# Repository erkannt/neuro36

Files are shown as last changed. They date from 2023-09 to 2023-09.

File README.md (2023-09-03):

# neuro36

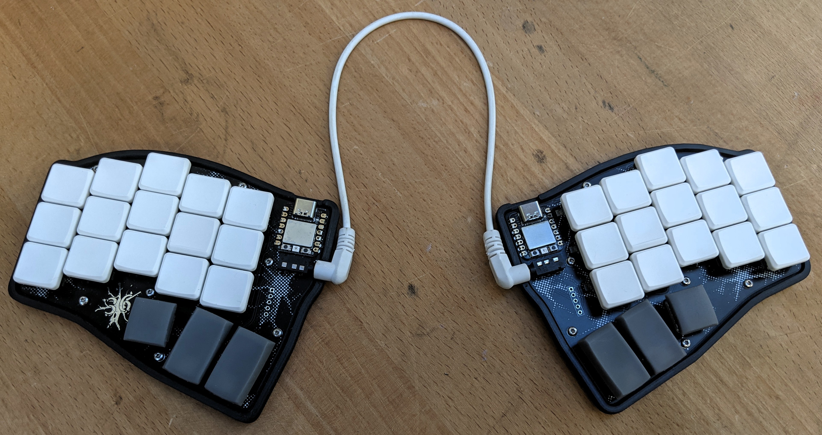
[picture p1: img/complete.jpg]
top down image of neuro36 split keyboard


- 36 key
- reversible PCB
- Xiao Seed RP2040 mcu
- choc-spaced
- remaining pins broken out on right hand  
  (hope was to add trackball)
- low profile printed case
- press fit travel protector
- silkscreen of real neurons  
  (EM image taken by my partner)
- hotswap or soldered mount of main 30 keys
- thumb keys can be soldered in either orientation

## Goals

I wanted a keyboard I could travel with. I need 36 keys and like to have larger keys to rest my thumbs on (probably due my journy having been Ergodox -> gergo).

I wanted to learn KiCAD and thanks to all the amazing open source keyboards out there it was a breeze.

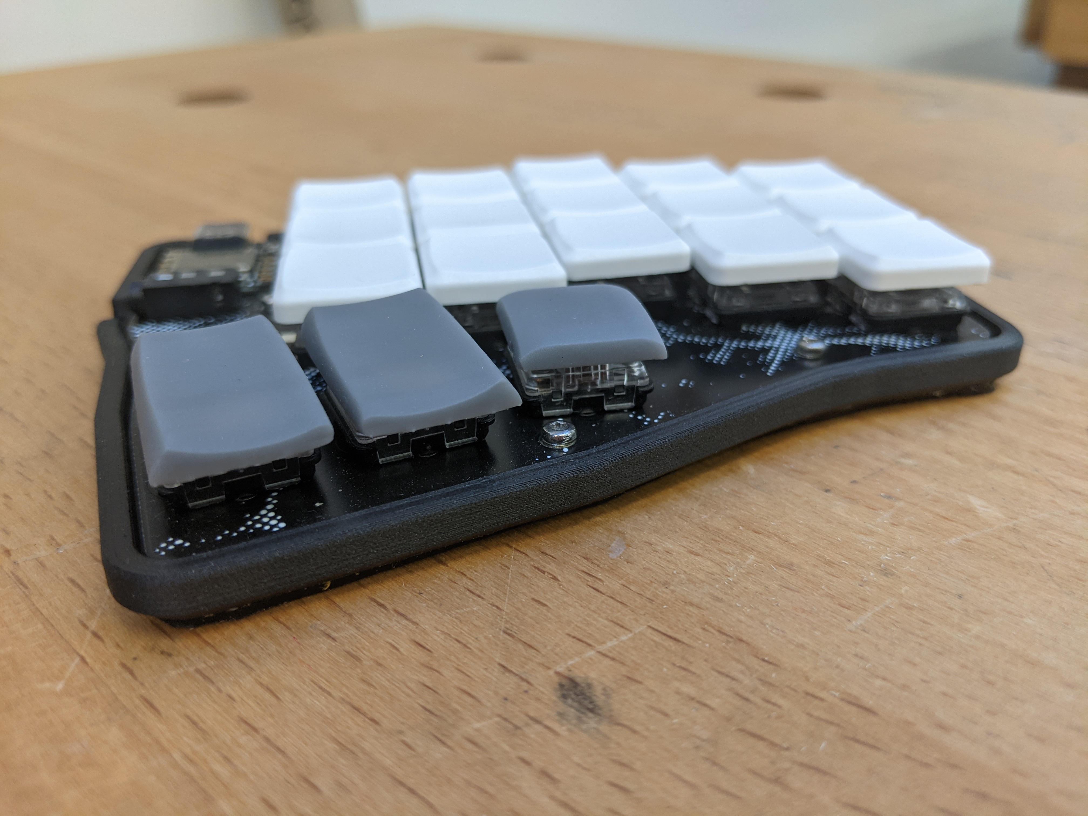
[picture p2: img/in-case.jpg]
case close up

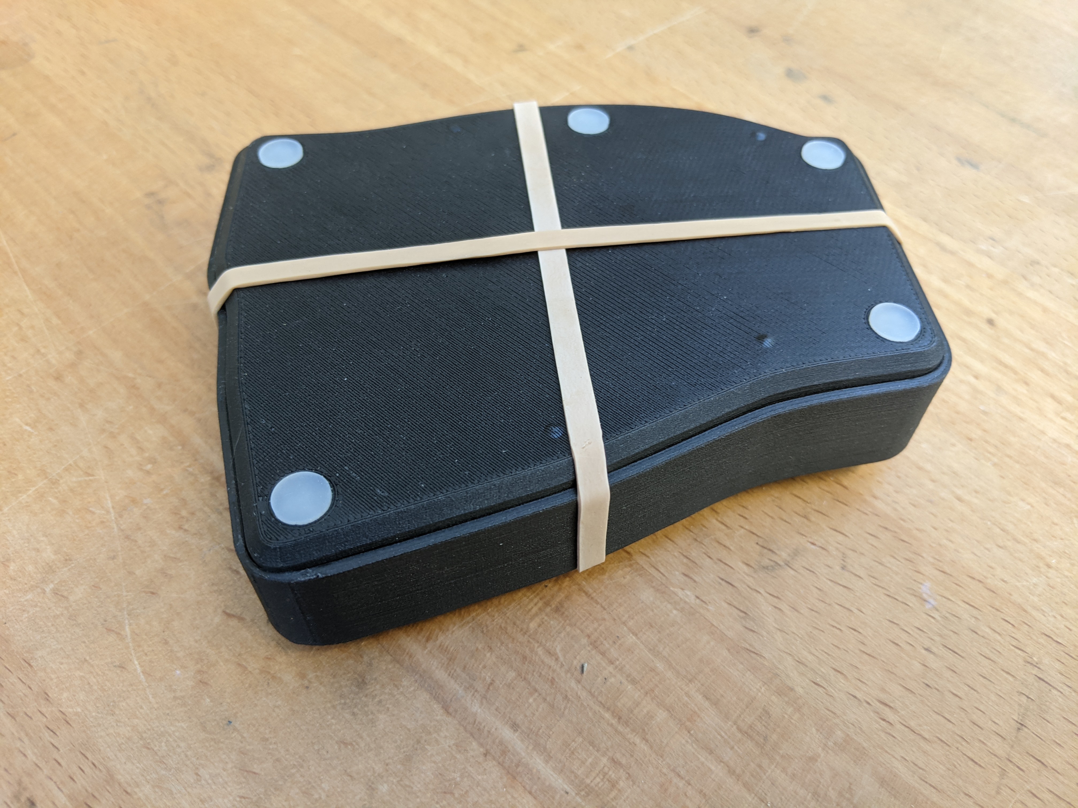
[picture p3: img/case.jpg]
case


## Making one

The [jlcpcb folder](/jlcpcb/) is what I sent off for manufacturing.
Five PCBs (enough for two keyboards) cost me 14.22 GBP incl. shipping and taxes.

The case is printable without supports, the travel protector needs supports. Make sure you have good bed adhesion and a warped print will give you a wobbly case.

Apart from the PCBs you will need:

- 36 choc switches
- keycaps (my thumbs are: [1u chicago steno](https://www.printables.com/model/158865-chicago-steno-low-profile-keycaps-kailh-choc/files#preview:file-oSJYS) and [1.5u chicago steno](https://www.printables.com/model/235527-thumb-15u-90deg-rotated-stem-fixed#preview:file-UjejR))
- TRRS cable
- heat press inserts (M2(ID) x 3.2mm(OD))
- screws (M2 x 5)
- TRRS jacks THT
- 1N4148WS SOD-323

I picked a very small diode footprint by accident. I'd suggest going for something larger if you are up for tweaking the KiCAD project.

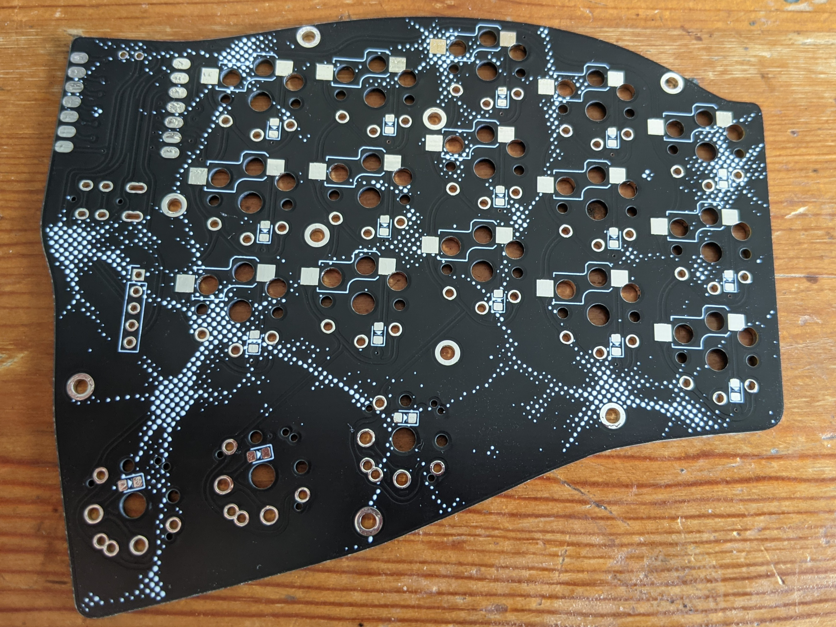
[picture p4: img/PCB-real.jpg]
neurons on pcb

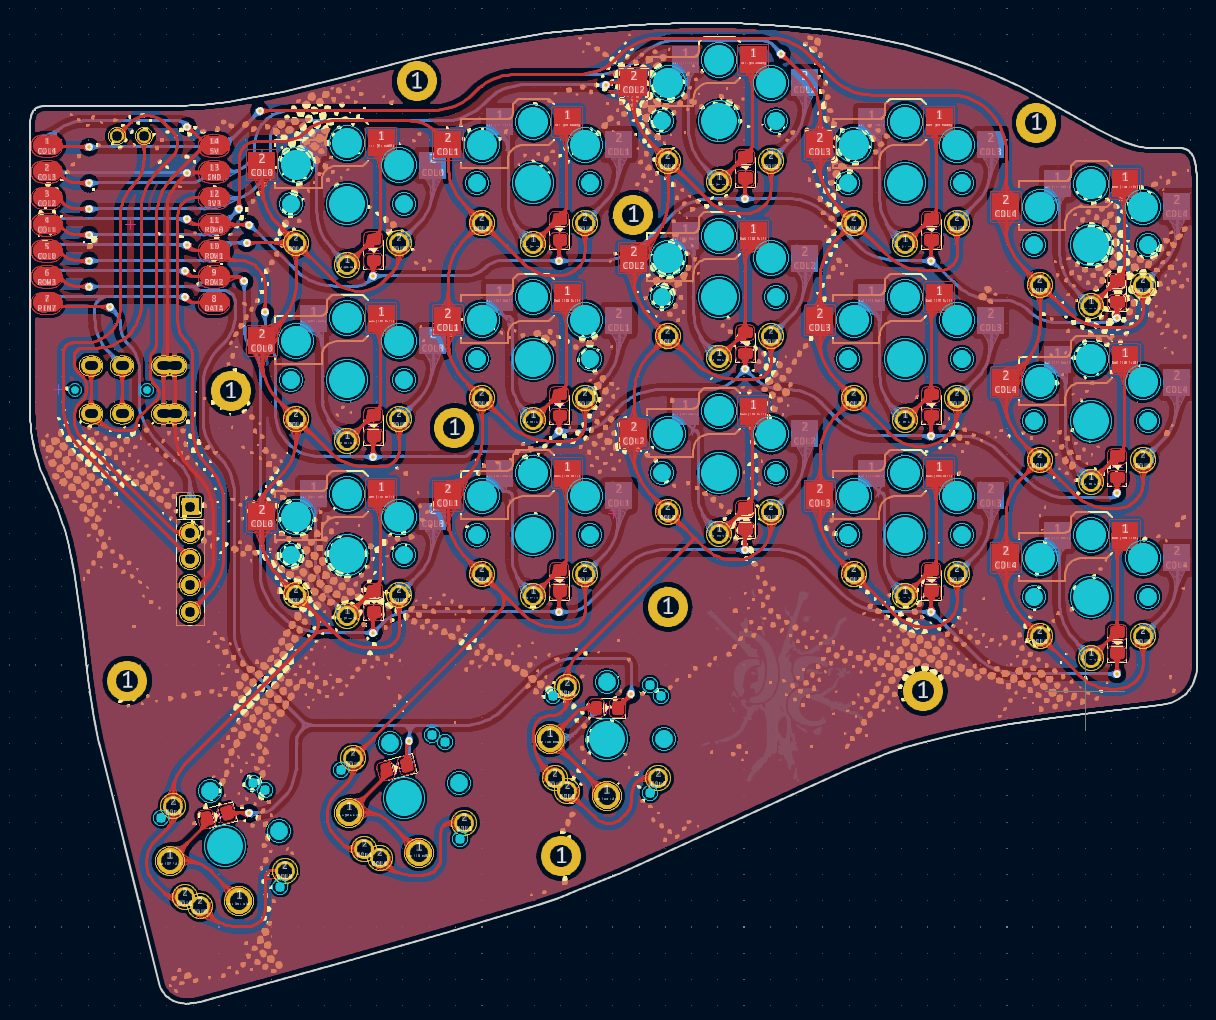
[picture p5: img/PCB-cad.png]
PCB in kicad


## Firmware

You can use my [unmerged QMK branch](https://github.com/erkannt/qmk_firmware/tree/neuro36/keyboards/neuro36) for this keyboard.

Someday I might try to get this merged.

Here is my current keymap.

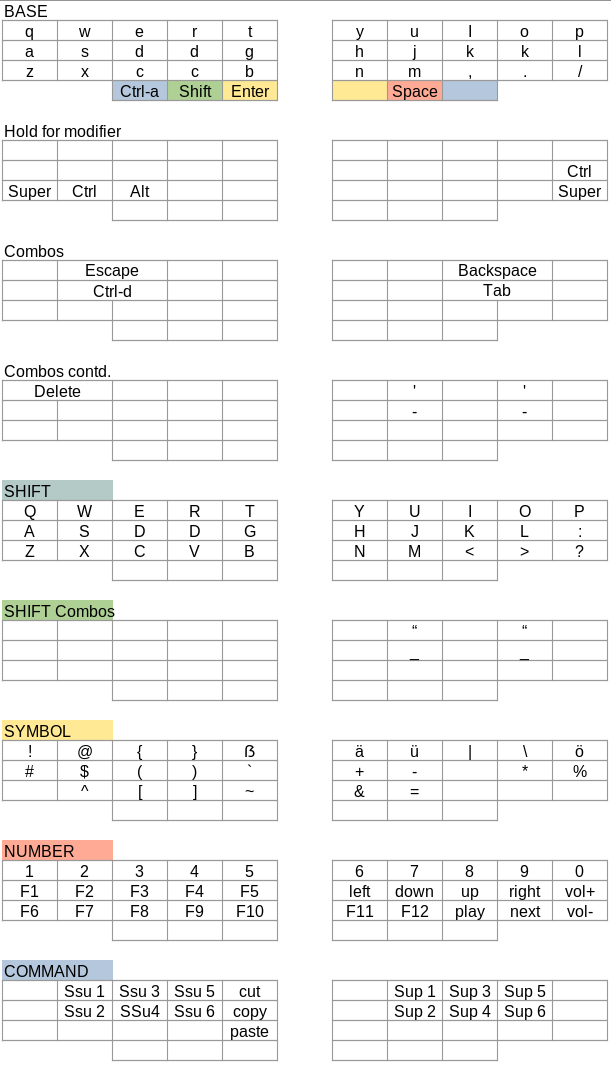
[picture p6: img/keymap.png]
keymap


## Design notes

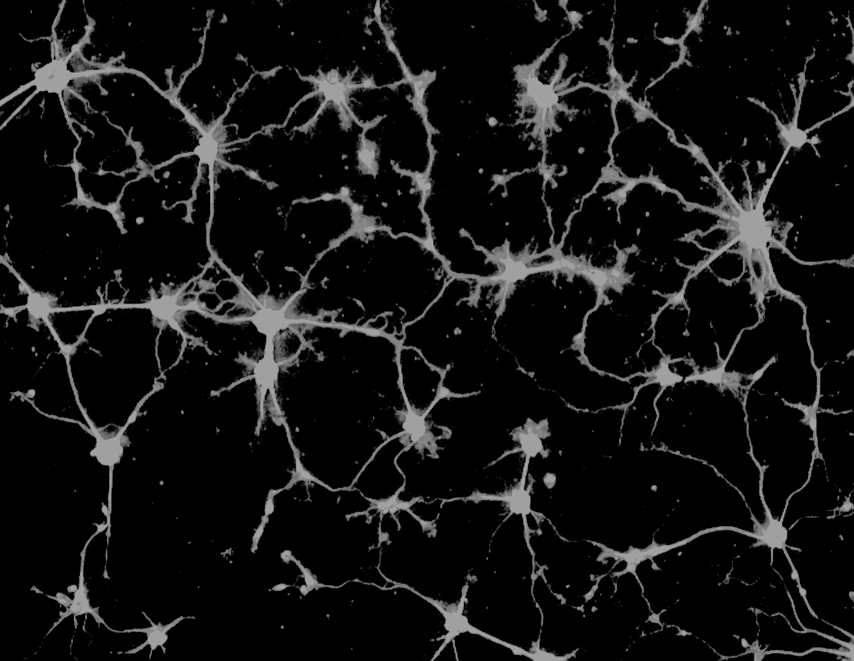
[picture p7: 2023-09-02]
artwork/neurons-bw.png

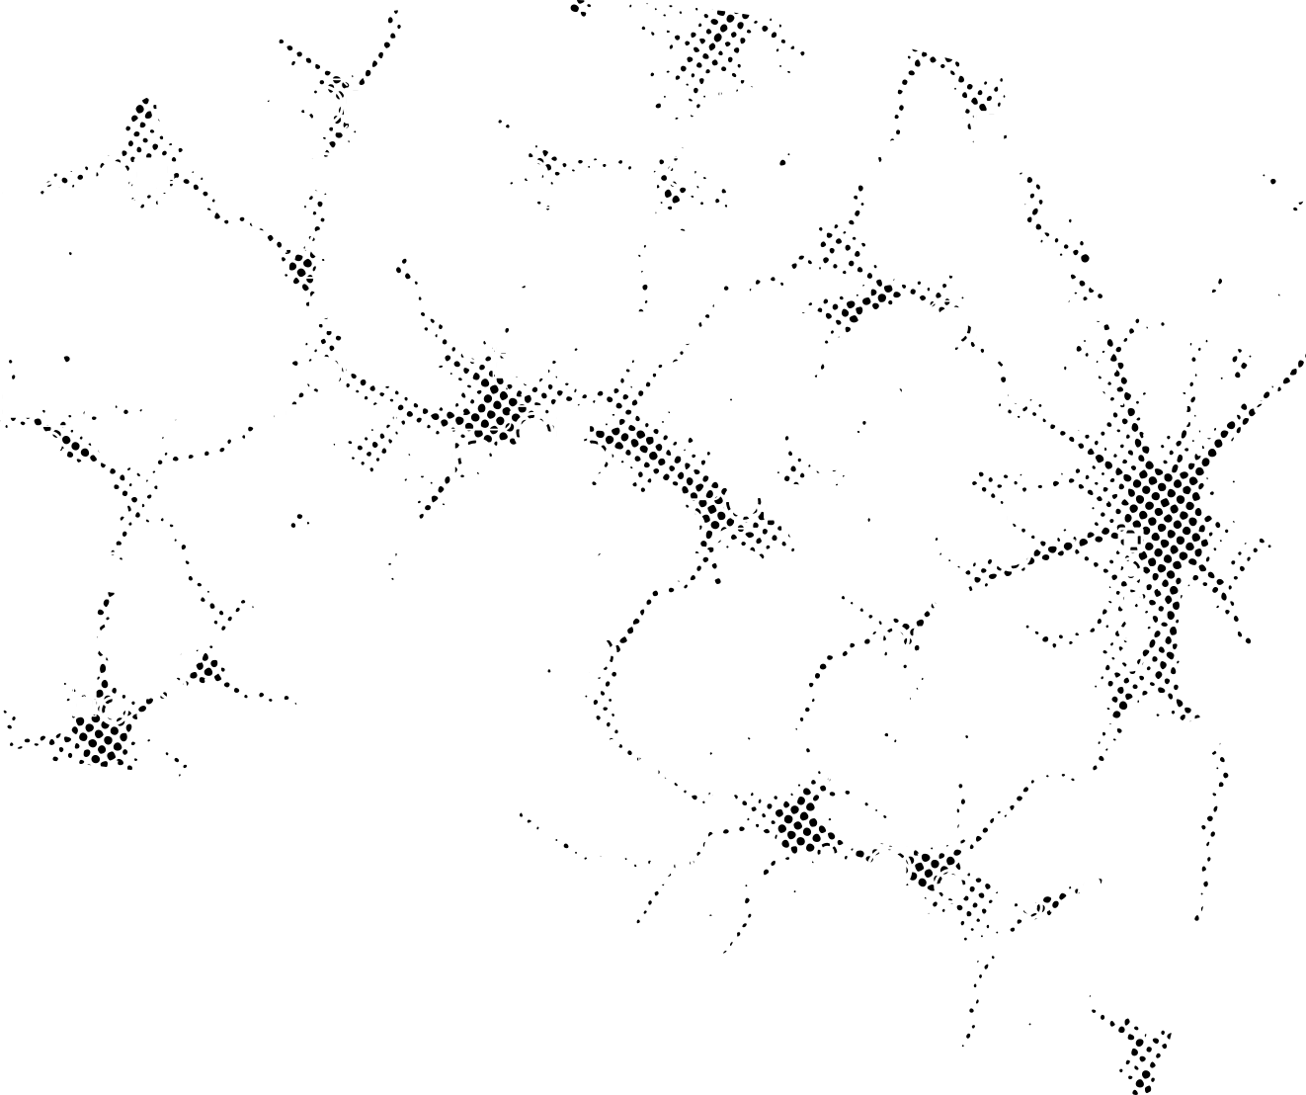
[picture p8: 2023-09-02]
artwork/neurons-left.png

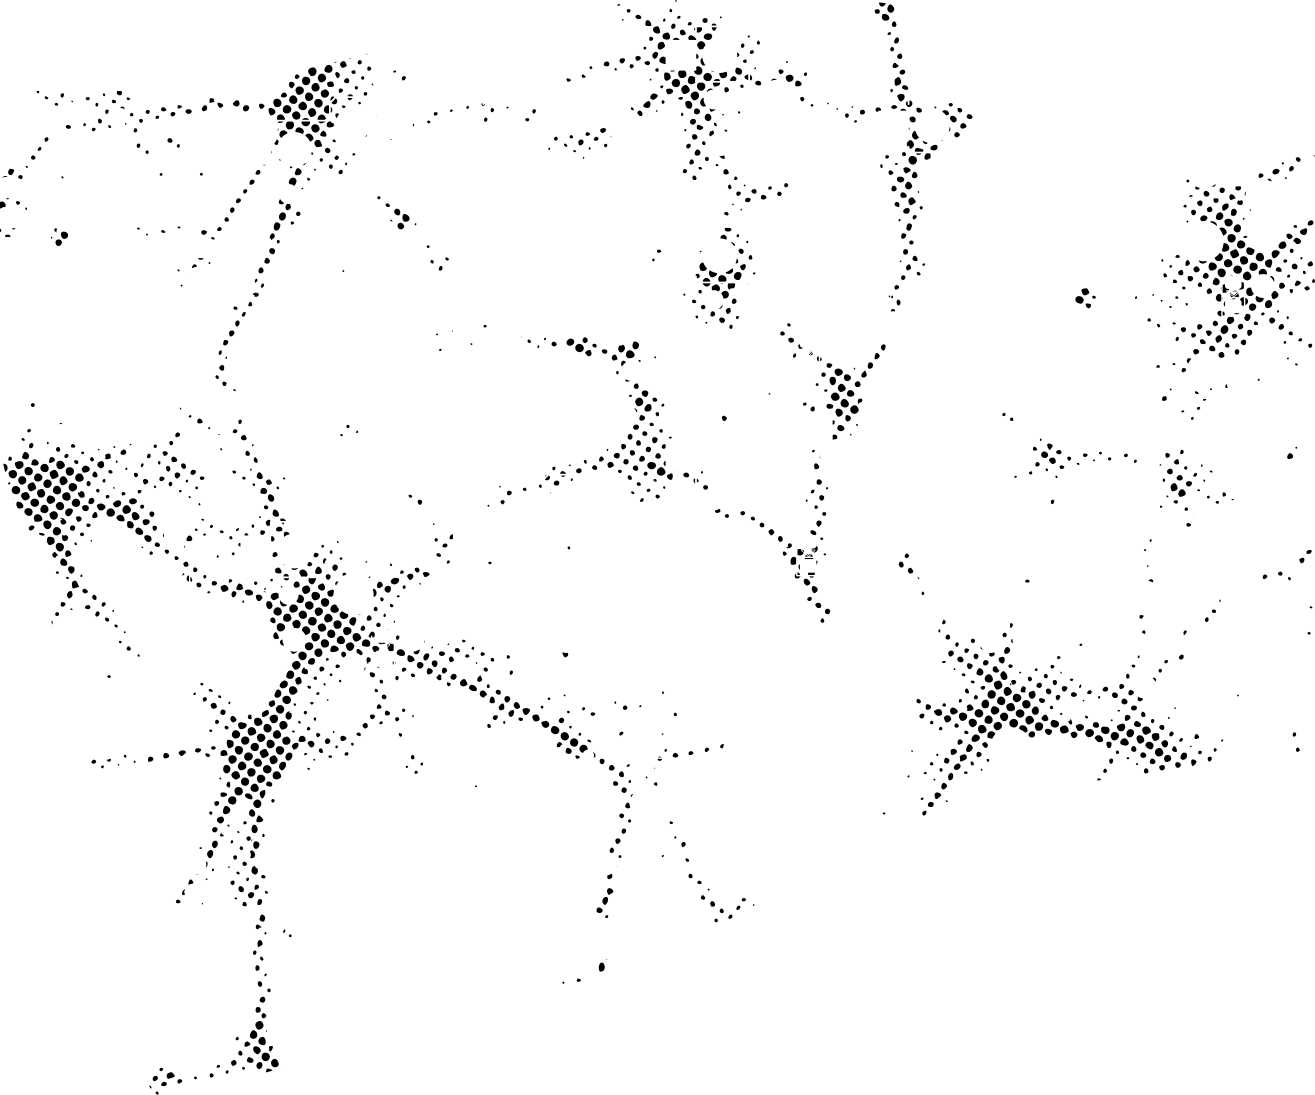
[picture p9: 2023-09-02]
artwork/neurons-right.png

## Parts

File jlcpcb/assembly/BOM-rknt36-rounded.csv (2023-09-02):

Comment | Designator | Footprint | LCSC
D | D31 | 0805_diode
SW_Push | SW9 | Kailh_socket_PG1350_optional_reversible
SW_Push | SW15 | Kailh_socket_PG1350_optional_reversible
D | D21 | 0805_diode
SW_Push | SW14 | Kailh_socket_PG1350_optional_reversible
SW_Push | SW6 | Kailh_socket_PG1350_optional_reversible
Conn_01x05 | J1 | PinHeader_1x05_P2.54mm_Vertical
D | D17 | 0805_diode
SW_Push | SW4 | Kailh_socket_PG1350_optional_reversible
D | D9 | 0805_diode
D | D15 | 0805_diode
SW_Push | SW13 | Kailh_socket_PG1350_optional_reversible
D | D7 | 0805_diode
D | D23 | 0805_diode
SW_Push | SW16 | SW_PG1350_reversible_rotatable
SW_Push | SW17 | SW_PG1350_reversible_rotatable
D | D19 | 0805_diode
D | D11 | 0805_diode
SW_Push | SW8 | Kailh_socket_PG1350_optional_reversible
SW_Push | SW3 | Kailh_socket_PG1350_optional_reversible
SW_Push | SW1 | Kailh_socket_PG1350_optional_reversible
D | D3 | 0805_diode
D | D1 | 0805_diode
D | D29 | 0805_diode
SW_Push | SW12 | Kailh_socket_PG1350_optional_reversible
SW_Push | SW5 | Kailh_socket_PG1350_optional_reversible
SW_Push | SW10 | Kailh_socket_PG1350_optional_reversible
D | D27 | 0805_diode
D | D33 | 0805_diode
TRRS | U3 | TRRS-PJ-320A
D | D13 | 0805_diode
D | D25 | 0805_diode
SW_Push | SW2 | Kailh_socket_PG1350_optional_reversible
SW_Push | SW11 | Kailh_socket_PG1350_optional_reversible
D | D35 | 0805_diode
xiao | U1 | xiao-smd
SW_Push | SW18 | SW_PG1350_reversible_rotatable
SW_Push | SW7 | Kailh_socket_PG1350_optional_reversible
D | D5 | 0805_diode
D | D12 | 0805_diode
D | D18 | 0805_diode
D | D36 | 0805_diode
D | D14 | 0805_diode
D | D30 | 0805_diode
D | D8 | 0805_diode
D | D6 | 0805_diode
xiao | U2 | xiao-smd
D | D10 | 0805_diode
D | D28 | 0805_diode
D | D4 | 0805_diode
D | D26 | 0805_diode
D | D22 | 0805_diode
D | D2 | 0805_diode
D | D16 | 0805_diode
D | D34 | 0805_diode
D | D32 | 0805_diode
D | D24 | 0805_diode
D | D20 | 0805_diode
TRRS | U4 | TRRS-PJ-320A
MountingHole | H3 | MountingHole_2.2mm_M2_DIN965_Pad
MountingHole | H1 | MountingHole_2.2mm_M2_DIN965_Pad
MountingHole | H7 | MountingHole_2.2mm_M2_DIN965_Pad
MountingHole | H5 | MountingHole_2.2mm_M2_DIN965_Pad
MountingHole | H4 | MountingHole_2.2mm_M2_DIN965_Pad
MountingHole | H10 | MountingHole_2.2mm_M2_DIN965_Pad
MountingHole | H6 | MountingHole_2.2mm_M2_DIN965_Pad
MountingHole | H8 | MountingHole_2.2mm_M2_DIN965_Pad
MountingHole | H2 | MountingHole_2.2mm_M2_DIN965_Pad

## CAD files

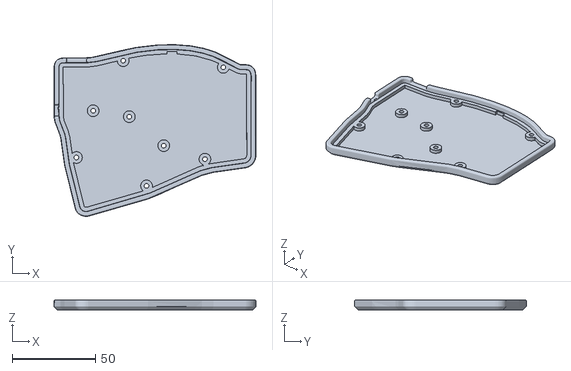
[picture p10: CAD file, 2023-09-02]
case/case-v3--rounded.stl
121.0 x 102.9 x 6.10

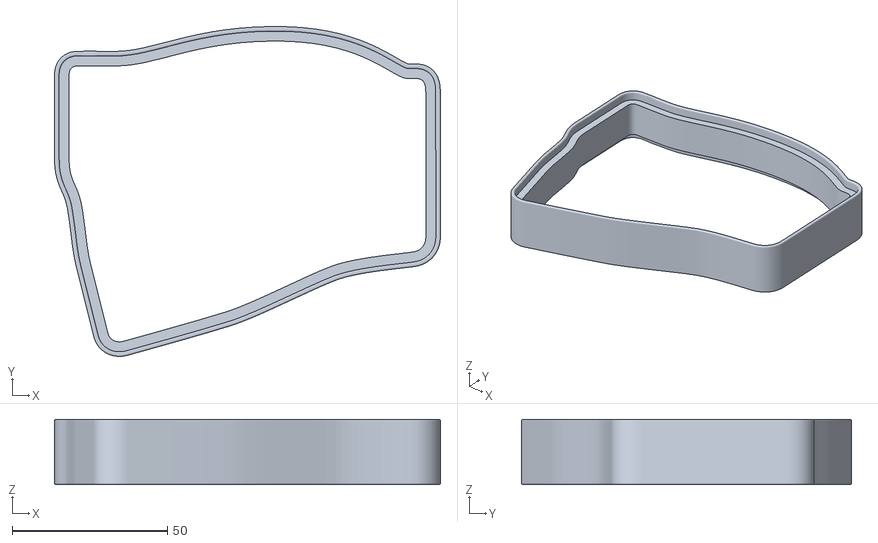
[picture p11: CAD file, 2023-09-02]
case/case-v3-combined-transport--rounded.stl
124.4 x 106.3 x 21.0

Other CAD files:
case/case-v3--rounded--mirrored.stl
case/case-v3-transport.blend
case/case-v3.blend

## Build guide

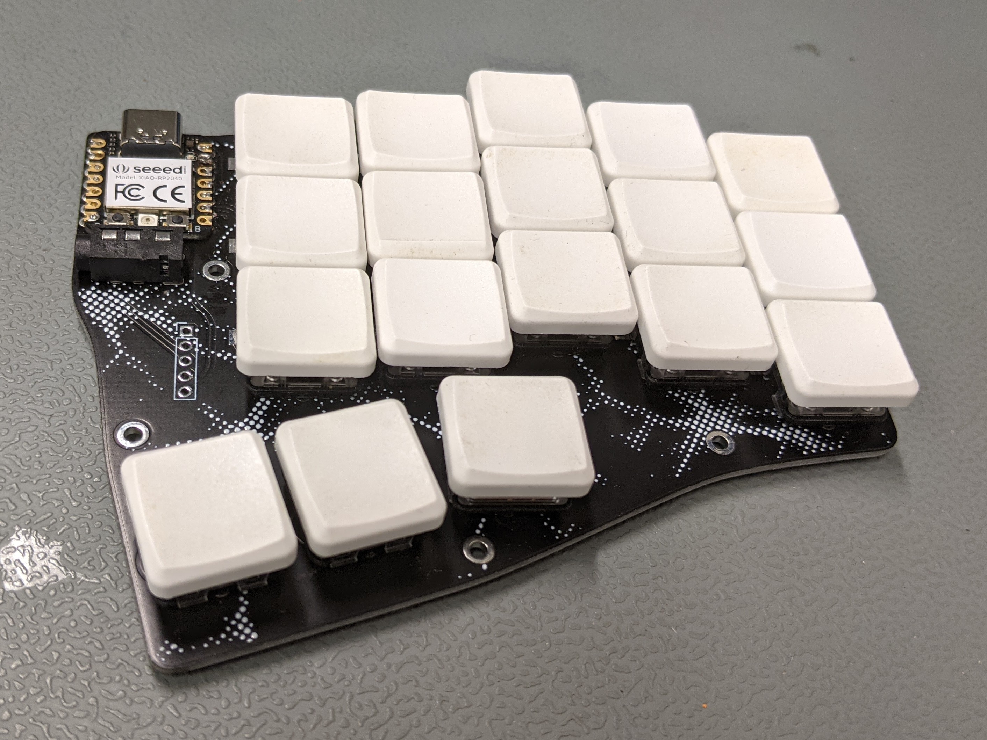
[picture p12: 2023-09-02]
img/right-soldering.jpg

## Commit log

2023-09-02 Dump of everything
    [#relevant-outlines.dxf, BOM-rknt36-rounded.csv, BOM-rknt36.csv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]
2023-09-02 Start moving files into folders
    [#relevant-outlines.dxf, bottom-v1.stl, case-outer.dxf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]
2023-09-02 Add kicad gitignore
2023-09-02 Remove old case files
    [#relevant-outlines.dxf, bottom-v1.stl, case-outer.dxf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]
2023-09-14 Add solderpad license
